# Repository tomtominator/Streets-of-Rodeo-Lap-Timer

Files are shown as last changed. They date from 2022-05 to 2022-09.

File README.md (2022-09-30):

# Streets-of-Rodeo-Lap-Timer

## Project Description  

As a de-stressing pastime, my brother and I ride our bikes around our driveway as fast as we can. How fast? This project helps us answer that question with precision. Our motion detecting lap timer is made from a custom built 4 digit 7 segement display for the timer, an ultrasonic distance sensor, and a cheap microcontroller. Its designed to be powered from a wall outlet. It consisted of lots of soldering LEDs, 3D printing for the LED cases, circuit design to ensure we weren't frying the microcontroller, and C++ code writing.  

### High Level Design Choices: 

The initial idea was to use a laser-type sensor that would trigger when we passed through. It wasn't ideal to have to place objects on both sides and possibly even have a wire tracing back over the track. I remembered using sonic distance sensors in physics class which only had 1 emitter fixing our problem. I also remembered them being suprisingly accurate and we only needed rough accuracy for our application. We happened to have a ultrasonic distance sensor and microcontroller lying around so we built the project around that.  

The original plan was to buy a 7 segment display but the largest ones our local [All Electronics](https://www.allelectronics.com/) had were 1"x3". We got this design working quickly but were unsatisfied because we couldn't easily see the digits during the day or while going around the driveway. So we build our own display using a modified design of the one we bought. Based on our calculations, this new display would draw about 1-1.5A which introduced a lot of problems with the initial design. We had to use transistors because the microcontroller couldn't provide the power needed through its pins, we needed to connect to an outside power source and provide 2 seperate voltages (1 for the board and 1 for the LEDS), and we needed to decide on the LED layout and soldering method for 200 some LEDS.  

Check out an older project: https://github.com/tomtominator/UnderglowProject  

## Finished Product

### Wooden Case and Sensor Case (Penguin)

Picture of box and punguin sensor 

Display board mounded to plywood box with main power switch and brightness dimmer mounted on the right side. The box is spray painted black to match the segments for a clean and professional look. A penguin themed 3d printed case for the distance sensor, raises it to the optimal 4 inches from the ground. Universal 3 prong power female power cable and 4 prong female sensor connectors are mounted on the bottom for easy setup and swappable cables.

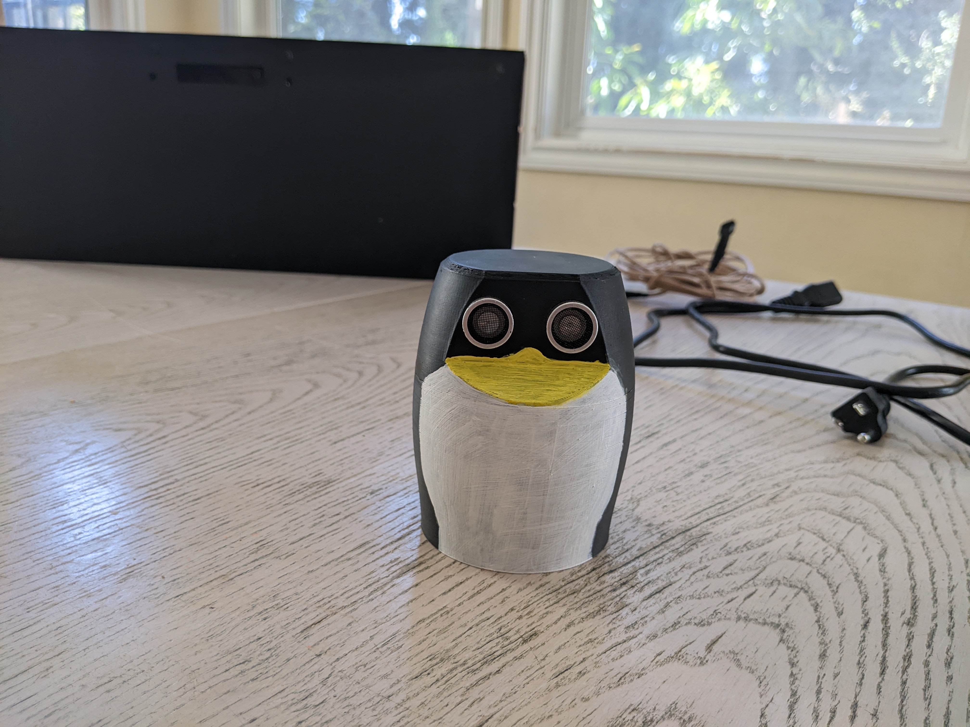
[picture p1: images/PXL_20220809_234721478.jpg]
Close up of penguin
 

Close up of penguin theme sensor case.

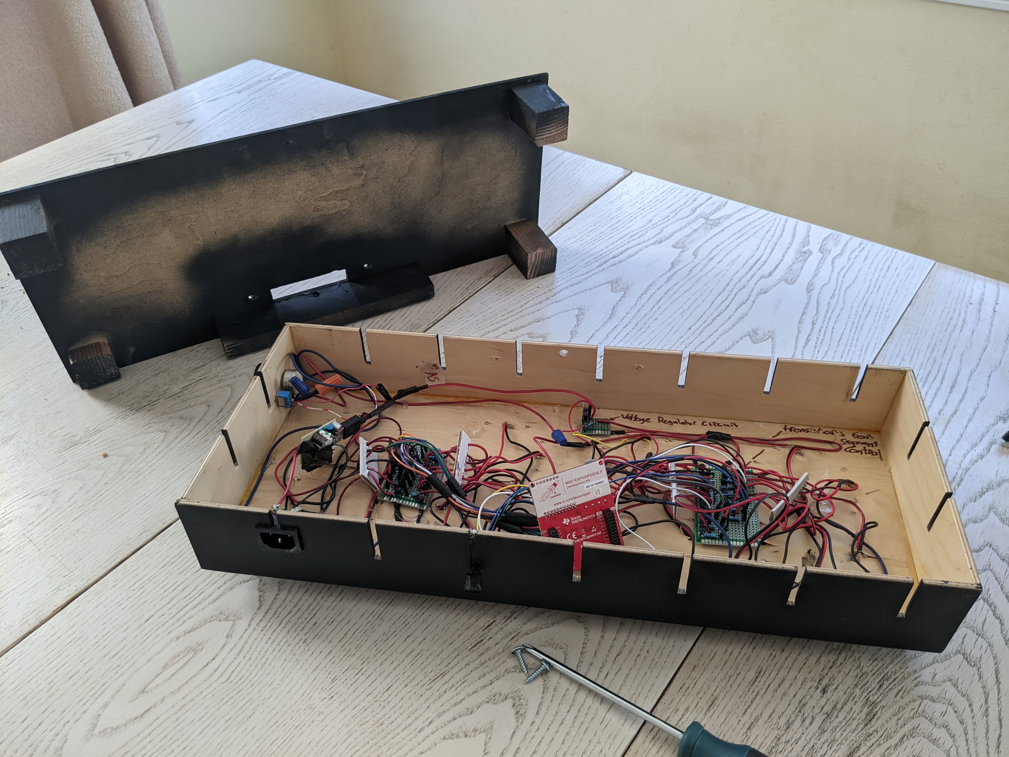
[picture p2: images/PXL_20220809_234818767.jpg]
Picture wooden case with back removed


View of the back cover easliy removed with the extraction of two screws on top of the case gives easy access to all components inside. 

# Detailed Construction

## Display

We modeled our custom 7 segment display off of this one we bought. It is a common anode display. This datasheet was useful: https://www.allelectronics.com/mas_assets/media/allelectronics2018/spec/FDA-5.pdf
### Circuit Diagrams
  
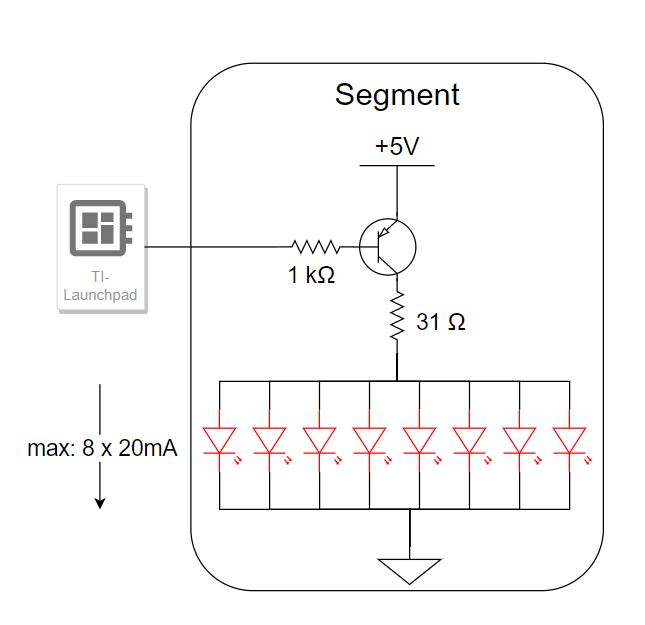
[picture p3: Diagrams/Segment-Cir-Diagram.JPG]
Segment Diagram
  

Above is the circuit diagram for a given segment. We will be running the LEDS at 20mA and controlling the segments with a PNP transistor switched by the launchpad. The 31 ohms was calculated to get the desired 20mA/LED number.

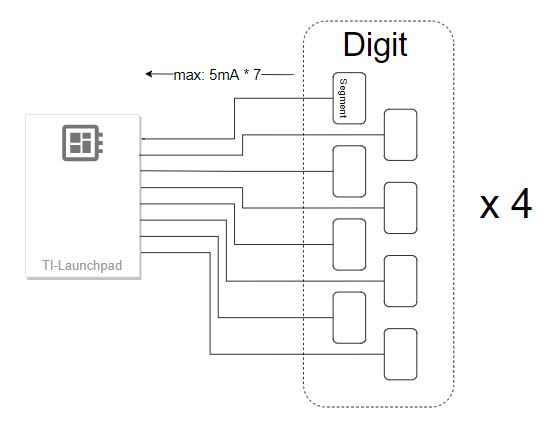
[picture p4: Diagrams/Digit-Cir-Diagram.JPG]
Digit Diagram
   

The 5mA current coming into the board per transistor is calculated using the hfe number provided by the transistor datasheet and this equation: I_C = (hfe) * I_B. For a PNP we are sinking current. The total current into the board is 35mA. The board must only dissapate about .175W. Note that only 1 digit is ever on at a time. The total draw of the digit from the power source is 160mA * 7 = 1.12A --at 5V--> 5.6W  

Our 7 segment display was slightly different from the standard design to make wiring easier. However, this made the pinout quite busy:  

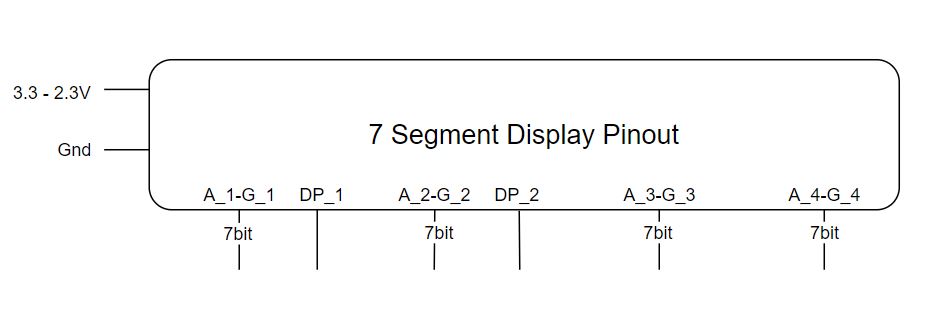
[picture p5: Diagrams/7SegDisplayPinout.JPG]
Custom 7 Segment Display Pinout
   

Luckily the launchpad has many i/o pins so this simplified our hardware and lighting up a sigle digit at a time could be done in the code (this single digit lighting is done to save on power and limit the current the launchpad has to sink).  
The distance sensor was connected to the launchpad as well. The whole assembly was controlled by C++ code run on the launchpad, switching all the segments and operating the distance sensor.
  
### Experimental Results

- Total segment current = 100mA - less than expected  
- Current into base of 2N3905 = 3.5mA  
- Transistor base resistance: 150 || 270 = 96 ohms  
- No need for resistors for each LED, the transistor base resistor on limits the current flow from emitter to collector  
- LEDS plenty bright at this power level, likely want to be able to reduce brightness with pot somehow

These results will give a general estimate to make sure we don't exceed any of our parts power limits. This is also a sanity check that calculations were done correctly.  

### Display Brightness

We had to use a voltage regulator to provide both 5 and a variable 3.3-2.3V from the 5V power supply. We used the LM317 variable voltage regulator with a 10K potentionmeter. This explanation video was extremely helpful: https://www.youtube.com/watch?v=IjJWWGPjc-w.  

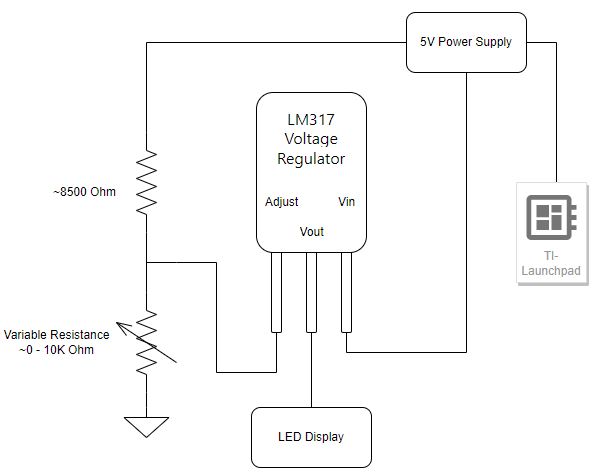
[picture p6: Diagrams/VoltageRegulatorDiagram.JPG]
Voltage Regulator Diagram
   

# Sensor and Code

The final version of the [code on the Launchpad](https://github.com/tomtominator/Streets-of-Rodeo-Lap-Timer/blob/main/LaunchPad%20Code/Lap_Time_Display_Custom_Final/Lap_Time_Display_Custom_Final.ino). The microcontroller was under-powered for the desired rapid operation of both the display and distance sensor. We worked to optimize the multitasking balance to get a solid display with rapid sensing for accurate lap times. Within the limitations of our materials I am satisfied but we have future plans to have 2 slow microcontrollers each doing one task and communicating (perhaps over wifi with the ardunio W). 

The operation of the distance sensor is slightly complicated but luckily there is plenty of code on the internet for this sensor. This is the explanation we used and base code we modified: https://create.arduino.cc/projecthub/abdularbi17/ultrasonic-sensor-hc-sr04-with-arduino-tutorial-327ff6  

Future Improvements:  
Make main loop event driven by performing certain functions every amount of millis() difference, instead of using counters to trigger actions. (This way we actually sample every 200ms for example)  
Make one of the digits a lap counter since we don't have hundreds place precision

# Physical Parts

### STL Files Descriptions

- 1 Segment File
Includes 8 holes for each led to be inserted and soldered on the back

- Slip in Plate
Accepts 1 segment plate to slip in firmly, allowing space for soldered connections. Wires are to be routed through the center hole in the back. Other 2 holes used for mounting to final backplate.

- 1 digit linked
Not included in our final design but would save alot of time and effort. Instead of printing segments individually this file includes 7 connected with proper spacing. Recommended for printers with ABL or a very nicely leveled bed. 

### Assembly
After 8 LEDs are soldered in paralell in each segment, power wires can be routed through the slip in plate, and the segment can be firmly inserted. (If using the individual plates, each should be mounted to a backplate prior to doing this.) 

Each segment with LEDs and power wires are pressed into their plates and all wires are routed through the slip in plate and through holes drilled in the backplate. All wires are easily accesable in the backplate for later connections to transistors and board. 

Segments could be painted matt black for a cleaner look.

All switches and pots can be mounted on the backplate 

# Links

## Ingredients:  

- HC-SR04 Ultrasonic Distance Sensor: https://www.amazon.com/SainSmart-HC-SR04-Ranging-Detector-Distance/dp/B004U8TOE6 
- 4-Digit 7 Segement Display (Deprecated): https://www.allelectronics.com/item/fda-5/4-digit-red-clock-display-0.4-digits/1.html  
- TI Launchpad MSP-EXP430F5529LP: https://www.ti.com/tool/MSP-EXP430F5529LP
- 232 Red LEDS: https://www.allelectronics.com/item/led-513/5mm-red-led/1.html
- 30 PNP Transistors: https://www.allelectronics.com/item/2n3905/2n3905-pnp-to-92-transistor/1.html
- LM317 Voltage Regulator
- Switch, 10K pot, lots of resistors(mostly 270ohm)

### Spec/Datasheets:  

- Transistors: https://www.mouser.com/datasheet/2/308/FairchildSemiconductor_16142055386277-1191860.pdf
- LEDS: https://www.allelectronics.com/mas_assets/media/allelectronics2018/spec/LED-513.pdf
- Launchpad: https://www.ti.com/lit/ug/slau533d/slau533d.pdf?ts=1653799657399
- Sensor: https://web.eece.maine.edu/~zhu/book/lab/HC-SR04%20User%20Manual.pdf
- Display: https://www.allelectronics.com/mas_assets/media/allelectronics2018/spec/FDA-5.pdf
- Voltage Regulator: https://www.ti.com/document-viewer/LM317A/datasheet/features-snvsac20075#SNVSAC20075

Daniel and Thomas Matthew 2022

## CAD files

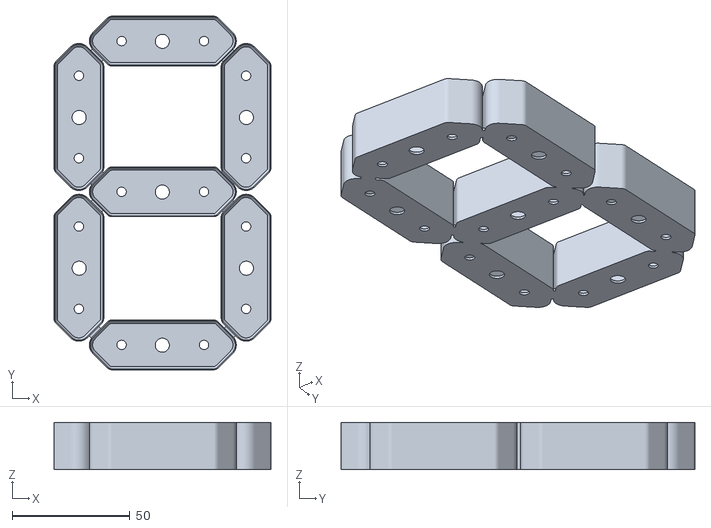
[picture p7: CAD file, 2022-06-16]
CAD Files/1 Digit linked.stl
92.1 x 150.1 x 20.0

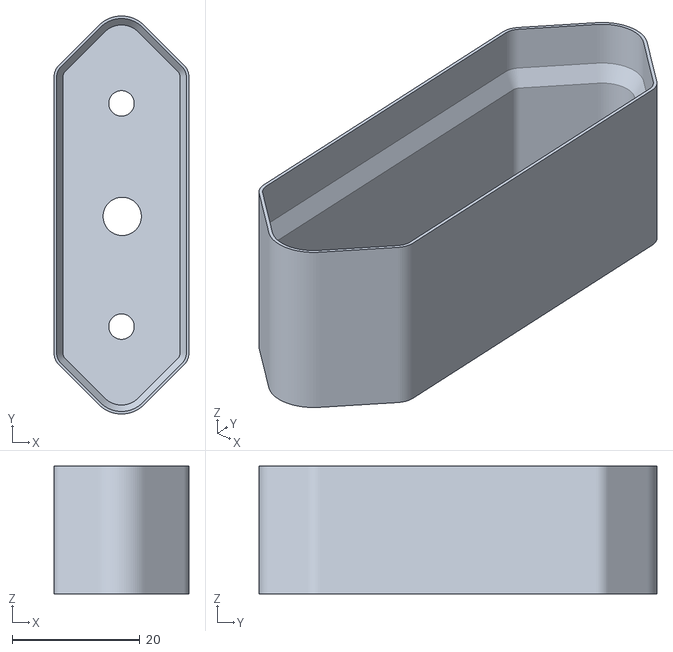
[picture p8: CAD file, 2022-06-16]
CAD Files/Slip In plate V2.stl
21.1 x 62.4 x 20.0

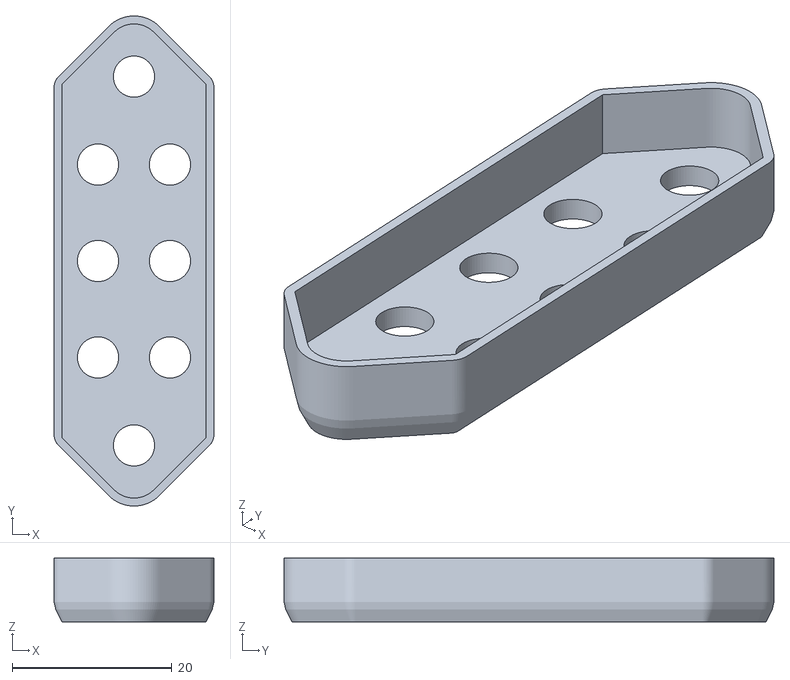
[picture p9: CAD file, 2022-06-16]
CAD Files/1 Segment V2.stl
20.0 x 61.3 x 8.00

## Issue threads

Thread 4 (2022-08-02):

Use Arduino Threads for Multitasking

tomtominator, 2022-08-02:
Improve main loop code with (Arduino Threads)[https://github.com/arduino-libraries/Arduino_Threads].

Benefits:
- Code easier to read
- Lower power
- can use with multiple cores in a future upgrade
- faster?

jfmatth, 2022-08-03:
This from the same article, might be an alternative

https://docs.arduino.cc/tutorials/generic/multiple-blinks

tomtominator, 2022-08-11:
It looks like the scheduler is only supported by Arduinos with SAMD architectures. Same thing with the threads. The chip on the TI board is not as powerful as I thought:
Our chip: https://www.ti.com/product/MSP430F5529#features
Ardunio Zero: https://www.microchip.com/en-us/product/ATsamd21g18

Might want to upgrade to the zero or similar ardunio...

jfmatth, 2022-08-11:
might be worth the upgrade (10bucks) just to use the library.

tomtominator, 2022-08-12:
A bit more than 10bucks, I think Daniel and I would rather go all in and get 2 Arduinos with Wifi and put 1 in the penguin.

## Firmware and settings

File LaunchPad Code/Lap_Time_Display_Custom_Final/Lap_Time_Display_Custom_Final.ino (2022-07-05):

// ---------- Lap Time Counter ----------
// Using Ultrasonic Sensor HC-SR04
// Base sensor code taken from: https://create.arduino.cc/projecthub/abdularbi17/ultrasonic-sensor-hc-sr04-with-arduino-tutorial-327ff6
// MSQC4911C Display data sheet: https://www.allelectronics.com/mas_assets/media/allelectronics2018/spec/FDA-5.pdf
//   Note: our custom display has a wire for each of the 30 segments (7 segment * 4 digit + 2 decimal places) where LOW = on, HIGH = off
//    but we only power 1 digit at a time to limit how much current the microcontroller has to sink. Powering 1 digit it sinks about 45mA
//   Note 2: pins 6_1 and 6_2 on the microcontroller don't work; can't write a high value to them

// Written by: Thomas Matthew 6/6/2022
// Last Updated: 7/1/22

// --- Feature Flags ---
// 1/0 values for enable/disable of certain sections of the code
#define DEBUG 0 // Enables/disables serial communication with computer for debugging


// --- End ---

//---Parameters---
// Note: all delays are estimates that don't include the time to execute the code, only the 'delay' lines. So they are bound to be lower than actual
#define REFRESH_RATE 20 // Decrease REFRESH_RATE to refresh digits quicker and sample more often
                        // Digit refreshes every REFERSH_RATE/4 and distance sensor samples evert REFERSH_RATE
                        // Note 1: LAP_COOLDOWN dependency on REFRESH_RATE
                        // Note 2: that sensor operation takes some time between displaying the digits but it micro sec vs milli sec (if sensor is not working properly it will be significant amount of time)
#define DIGIT_UPDATE_COOLDOWN 5 // Update ongoing_lap_time and displayed digits every DIGIT_UPDATE_COOLDOWN * REFRESH_RATE(20) = 100ms = .1sec
#define SENSE_COOLDOWN 10 // Only operate the sensor every SENSE_COOLDOWN loops of the main loop (sense rate: SENSE_COOLDOWN * REFRESH_RATE = 200ms)
#define LAP_COOLDOWN 125 //Laps can happen only every LAP_COOLDOWN(125) * REFRESH_RATE(20) = 2.5 sec
#define PASS_DIS_CHANGE 30 // Distance decreases by this much for a valid pass - lower to make more sensitive. Raise to decrease noise
#define WOBBLE 10 // Distance sensor must change by more than this to even consider an object has passed
//---End Parameters---

// ---------------- LAP TIME MEASUREMENT + HC-SR04 SECTION ----------------

#define echoPin P8_2
#define trigPin P8_1

// Variables for distance sensor
long duration; // duration of sound wave travel
int distance; //  distance measurement
int last_distance;
int laps; // number of times a object passes
int lap_cooldown_cnt;
int sense_cooldown_cnt;
int digit_update_cooldown_cnt;

float lap_time; //Lap time in ms
float ongoing_lap_time;
long lap_start;
long lap_end;
// ---------------- END ----------------


// ---------------- CUSTOM 7 SEGMENT DISPLAY SECTION ----------------

// Unfortunate Note: ABC.. wiring is reflected across xy plane. 
//                   Ording of letters represents ordering of wires into the microcontroller. ie P6_5 is adjacent to P3_4. and 6_5 was originally meant to be segment A_1
//                   ABCDEFG -> ECBAFEG (this is not the case for all digits) (we were rushed when wiring this unfortunately)
//                   (for digit 1 FEG -> GEF)
// Digit Pins:
  //1st Digit  
  #define D_1 P6_5 // blue
  #define C_1 P3_4 // 
  #define B_1 P3_3 // 
  #define A_1 P1_6 // 
  #define G_1 P6_6 // 
  #define E_1 P3_2 // 
  #define F_1 P2_7 // red 
  #define DP_1 P3_5 // black
  //2nd Digit
  #define D_2 P6_0 // purple 
  #define C_2 P6_1 // 
  #define B_2 P4_0 // 
  #define A_2 P4_2 // 
  #define F_2 P6_4 // 
  #define E_2 P7_0 // 
  #define G_2 P3_6 // black
  #define DP_2 P4_1 // red
  //3rd Digit //ABCDEF->GEFABCD
  #define G_3 P2_5 // black
  #define E_3 P2_4 // 
  #define F_3 P1_5 // 
  #define A_3 P1_4 // 
  #define B_3 P1_3 // 
  #define C_3 P1_2 // 
  #define D_3 P4_3 // gray
  //4th Digit
  #define D_4 P2_0 // red
  #define C_4 P2_2 // 
  #define B_4 P7_4 // 
  #define A_4 P3_0 // 
  #define F_4 P3_1 // 
  #define E_4 P2_6 // 
  #define G_4 P2_3 // orange


// Truth table for segements for digit
// ith Row holds the segments for the ith digit in A,B,C, ... order
// 1 value indicates light up that segment
int dsegs[10][7] = {
  {1, 1, 1, 1, 1, 1, 0}, /*0*/
  {0, 1, 1, 0, 0, 0, 0}, /*1*/
  {1, 1, 0, 1, 1, 0, 1}, /*2*/
  {1, 1, 1, 1, 0, 0, 1}, /*3*/
  {0, 1, 1, 0, 0, 1, 1}, /*4*/
  {1, 0, 1, 1, 0, 1, 1}, /*5*/
  {1, 0, 1, 1, 1, 1, 1}, /*6*/
  {1, 1, 1, 0, 0, 0, 0}, /*7*/
  {1, 1, 1, 1, 1, 1, 1}, /*8*/
  {1, 1, 1, 1, 0, 1, 1}  /*9*/
  };

//Decimal number to be displayed (converted to display_*)
float display_number;
int temp;

// These set what digits are being displayed
int display_digit_1;
int display_digit_2;
int display_digit_3;
int display_digit_4;
int decimal_place; //encodes where to place decimal point
// (1, ones number, 2 tens number, 3 hundreds number, 4 thousands number)
// ---------------- END ----------------

void setup() {
  laps = 1;
  pinMode(trigPin, OUTPUT);
  pinMode(echoPin, INPUT);
  if (DEBUG) {
    Serial.begin(9600); 
    Serial.println("Ultrasonic Sensor HC-SR04 Test"); 
    Serial.println("with TI Launchpad MSP-EXP430F5529LP");
  }

  lap_cooldown_cnt = 0;
  sense_cooldown_cnt = 0;
  digit_update_cooldown_cnt = 0;

  // ----------------------------------------------------
  pinMode(A_1, OUTPUT);
  pinMode(B_1, OUTPUT);
  pinMode(C_1, OUTPUT);
  pinMode(D_1, OUTPUT);
  pinMode(E_1, OUTPUT);
  pinMode(F_1, OUTPUT);
  pinMode(G_1, OUTPUT);
  pinMode(DP_1, OUTPUT);

  pinMode(A_2, OUTPUT);
  pinMode(B_2, OUTPUT);
  pinMode(C_2, OUTPUT);
  pinMode(D_2, OUTPUT);
  pinMode(E_2, OUTPUT);
  pinMode(F_2, OUTPUT);
  pinMode(G_2, OUTPUT);
  pinMode(DP_2, OUTPUT);

  pinMode(A_3, OUTPUT);
  pinMode(B_3, OUTPUT);
  pinMode(C_3, OUTPUT);
  pinMode(D_3, OUTPUT);
  pinMode(E_3, OUTPUT);
  pinMode(F_3, OUTPUT);
  pinMode(G_3, OUTPUT);
  //pinMode(DP_3, OUTPUT); no DP 3

  pinMode(A_4, OUTPUT);
  pinMode(B_4, OUTPUT);
  pinMode(C_4, OUTPUT);
  pinMode(D_4, OUTPUT);
  pinMode(E_4, OUTPUT);
  pinMode(F_4, OUTPUT);
  pinMode(G_4, OUTPUT);
  //pinMode(DP_4, OUTPUT); no DP 4
}

void loop() {
  
  // Get Time + Operate Sensor:
  if (lap_cooldown_cnt > LAP_COOLDOWN && digit_update_cooldown_cnt > DIGIT_UPDATE_COOLDOWN) {
    //----Lap Time Measurement----
    lap_end = millis();
    ongoing_lap_time = lap_end - lap_start;
    ongoing_lap_time = ongoing_lap_time / 1000;
    digit_update_cooldown_cnt = 0;

    // ---- SENSE ----
    if (sense_cooldown_cnt > SENSE_COOLDOWN) {
      sense_cooldown_cnt = 0;

      //----Measure Distance using HC-SR04----
      digitalWrite(trigPin, LOW); // Clears the trigPin condition
      delayMicroseconds(2);
      digitalWrite(trigPin, HIGH); // Sets the trigPin HIGH (ACTIVE) for 10 microseconds
      delayMicroseconds(10);
      digitalWrite(trigPin, LOW);
      duration = pulseIn(echoPin, HIGH); // Reads the echoPin, returns the sound wave travel time in microseconds
      // Calculating the distance
      distance = duration * 0.034 / 2; // Speed of sound wave divided by 2 (go and back)
      if (DEBUG) {
        Serial.print("Sensed Distance:  ");
        Serial.println(distance);
        Serial.print("Last Distance:  ");
        Serial.println(last_distance);
      }
      // Object Passed if distance decreased by at least PASS_DIS_CHANGE 
      //    Note: object must be further than PASS_DIS_CHANGE
      if ((distance - PASS_DIS_CHANGE) > 0 && !((last_distance - WOBBLE) < distance && distance < (last_distance + WOBBLE)) && (distance - PASS_DIS_CHANGE) < last_distance) { 
        lap_time = ongoing_lap_time;
        laps = laps + 1;
        lap_cooldown_cnt = 0;
        lap_start = millis();
        if (DEBUG) {
          Serial.println("------------------------Object passed----------------------");
          Serial.print("Lap Number: ");
          Serial.println(laps);
          Serial.print("Lap Time: ");
          Serial.println(lap_time);
        }
      }
      last_distance = distance;
    }
  }

  // Update Counters:
  lap_cooldown_cnt = lap_cooldown_cnt + 1;
  sense_cooldown_cnt = sense_cooldown_cnt + 1;
  digit_update_cooldown_cnt = digit_update_cooldown_cnt + 1;


  // ------------------- DISPLAY RECORDED TIME -------------------

  // Update Digit we are Displaying:
  if (sense_cooldown_cnt == 1 || lap_cooldown_cnt == 1 || digit_update_cooldown_cnt == 1) {
    //Display lap time for [LAP_COOLDOWN] seconds after object passes
    // else display the time spent in current lap
    if (lap_cooldown_cnt < LAP_COOLDOWN) {
      display_number = lap_time;
    } else {
      display_number = ongoing_lap_time;
    }

    //Get the first 4 digits of input unsigned long
    if (display_number > 1000) {      temp = display_number;          decimal_place = 4;
    } else if(display_number > 100) { temp = display_number * 10;     decimal_place = 3;
    } else if(display_number > 10) {  temp = display_number * 100;    decimal_place = 2;
    } else {                        temp = display_number * 1000;   decimal_place = 1; }
    display_digit_1 = temp / 1000;
    display_digit_2 = (temp / 100) % 10;
    display_digit_3 = (temp / 10) % 10;
    display_digit_4 = temp % 10;
  }
  
  // --- DISPLAY DIGITS ---
  // by scanning through them
  // --- 1st Digit ---
  if (dsegs[display_digit_1][0] == 1) { digitalWrite(A_1, LOW); } else { digitalWrite(A_1, HIGH); }
  if (dsegs[display_digit_1][1] == 1) { digitalWrite(B_1, LOW); } else { digitalWrite(B_1, HIGH); }
  if (dsegs[display_digit_1][2] == 1) { digitalWrite(C_1, LOW); } else { digitalWrite(C_1, HIGH); }
  if (dsegs[display_digit_1][3] == 1) { digitalWrite(D_1, LOW); } else { digitalWrite(D_1, HIGH); }
  if (dsegs[display_digit_1][4] == 1) { digitalWrite(E_1, LOW); } else { digitalWrite(E_1, HIGH); }
  if (dsegs[display_digit_1][5] == 1) { digitalWrite(F_1, LOW); } else { digitalWrite(F_1, HIGH); }
  if (dsegs[display_digit_1][6] == 1) { digitalWrite(G_1, LOW); } else { digitalWrite(G_1, HIGH); }
  if (decimal_place == 1 ) { digitalWrite(DP_1, LOW); } else { digitalWrite(DP_1, HIGH); }

  delay(REFRESH_RATE/4);
  //Turn off digit:
  digitalWrite(A_1, HIGH);
  digitalWrite(B_1, HIGH);
  digitalWrite(C_1, HIGH);
  digitalWrite(D_1, HIGH);
  digitalWrite(E_1, HIGH);
  digitalWrite(F_1, HIGH);
  digitalWrite(G_1, HIGH);
  digitalWrite(DP_1, HIGH);

  // --- 2nd Digit ---
  if (dsegs[display_digit_2][0] == 1) { digitalWrite(A_2, LOW); } else { digitalWrite(A_2, HIGH); }
  if (dsegs[display_digit_2][1] == 1) { digitalWrite(B_2, LOW); } else { digitalWrite(B_2, HIGH); }
  if (dsegs[display_digit_2][2] == 1) { digitalWrite(C_2, LOW); } else { digitalWrite(C_2, HIGH); }
  if (dsegs[display_digit_2][3] == 1) { digitalWrite(D_2, LOW); } else { digitalWrite(D_2, HIGH); }
  if (dsegs[display_digit_2][4] == 1) { digitalWrite(E_2, LOW); } else { digitalWrite(E_2, HIGH); }
  if (dsegs[display_digit_2][5] == 1) { digitalWrite(F_2, LOW); } else { digitalWrite(F_2, HIGH); }
  if (dsegs[display_digit_2][6] == 1) { digitalWrite(G_2, LOW); } else { digitalWrite(G_2, HIGH); }
  if (decimal_place == 2 ) { digitalWrite(DP_2, LOW); } else { digitalWrite(DP_2, HIGH); }

  delay(REFRESH_RATE/4);
  //Turn off digit:
  digitalWrite(A_2, HIGH);
  digitalWrite(B_2, HIGH);
  digitalWrite(C_2, HIGH);
  digitalWrite(D_2, HIGH);
  digitalWrite(E_2, HIGH);
  digitalWrite(F_2, HIGH);
  digitalWrite(G_2, HIGH);
  digitalWrite(DP_2, HIGH);

  // --- 3rd Digit ---
  if (dsegs[display_digit_3][0] == 1) { digitalWrite(A_3, LOW); } else { digitalWrite(A_3, HIGH); }
  if (dsegs[display_digit_3][1] == 1) { digitalWrite(B_3, LOW); } else { digitalWrite(B_3, HIGH); }
  if (dsegs[display_digit_3][2] == 1) { digitalWrite(C_3, LOW); } else { digitalWrite(C_3, HIGH); }
  if (dsegs[display_digit_3][3] == 1) { digitalWrite(D_3, LOW); } else { digitalWrite(D_3, HIGH); }
  if (dsegs[display_digit_3][4] == 1) { digitalWrite(E_3, LOW); } else { digitalWrite(E_3, HIGH); }
  if (dsegs[display_digit_3][5] == 1) { digitalWrite(F_3, LOW); } else { digitalWrite(F_3, HIGH); }
  if (dsegs[display_digit_3][6] == 1) { digitalWrite(G_3, LOW); } else { digitalWrite(G_3, HIGH); }
  
  delay(REFRESH_RATE/4);
  digitalWrite(A_3, HIGH);
  digitalWrite(B_3, HIGH);
  digitalWrite(C_3, HIGH);
  digitalWrite(D_3, HIGH);
  digitalWrite(E_3, HIGH);
  digitalWrite(F_3, HIGH);
  digitalWrite(G_3, HIGH);

// -- 4th Digit ---
  if (dsegs[display_digit_4][0] == 1) { digitalWrite(A_4, LOW); } else { digitalWrite(A_4, HIGH); }
  if (dsegs[display_digit_4][1] == 1) { digitalWrite(B_4, LOW); } else { digitalWrite(B_4, HIGH); }
  if (dsegs[display_digit_4][2] == 1) { digitalWrite(C_4, LOW); } else { digitalWrite(C_4, HIGH); }
  if (dsegs[display_digit_4][3] == 1) { digitalWrite(D_4, LOW); } else { digitalWrite(D_4, HIGH); }
  if (dsegs[display_digit_4][4] == 1) { digitalWrite(E_4, LOW); } else { digitalWrite(E_4, HIGH); }
  if (dsegs[display_digit_4][5] == 1) { digitalWrite(F_4, LOW); } else { digitalWrite(F_4, HIGH); }
  if (dsegs[display_digit_4][6] == 1) { digitalWrite(G_4, LOW); } else { digitalWrite(G_4, HIGH); }

  delay(REFRESH_RATE/4);
  digitalWrite(A_4, HIGH);
  digitalWrite(B_4, HIGH);
  digitalWrite(C_4, HIGH);
  digitalWrite(D_4, HIGH);
  digitalWrite(E_4, HIGH);
  digitalWrite(F_4, HIGH);
  digitalWrite(G_4, HIGH);



  // ------------------------------------------------------------
  //delay(REFRESH_RATE);
}

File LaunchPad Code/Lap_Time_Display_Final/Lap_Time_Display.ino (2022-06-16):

// ---------- Lap Time Counter ----------
// Using Ultrasonic Sensor HC-SR04
// Base code taken from: https://create.arduino.cc/projecthub/abdularbi17/ultrasonic-sensor-hc-sr04-with-arduino-tutorial-327ff6
// MSQC4911C Display data sheet: https://www.allelectronics.com/mas_assets/media/allelectronics2018/spec/FDA-5.pdf
// Written by: Thomas Matthew 5/27/2022


// ---------------- LAP TIME MEASUREMENT + HC-SR04 SECTION ----------------
#define echoPin P6_0
#define trigPin P6_1


#define SAMPLE_RATE 50 //Sample every 50ms = .05s
#define LAP_COOLDOWN 40 //Laps can happen only every LAP_COOLDOWN * SAMPLE_RATE (= 2) sec

#define WOBBLE 5 // Must change more than this range to be considered a real change in measured distance
#define PASS_DIS_CHANGE 30 // Distance decreases by this much for a valid pass - lower to make more sensitive. Raise to decrease noise

// Define Variables
long duration; // duration of sound wave travel
int distance; //  distance measurement
int last_distance;
int laps; // number of times a object passes
int lap_cooldown_cnt;

float lap_time; //Lap time in ms
float ongoing_lap_time;
long lap_start;
long lap_end;
// ---------------- END ----------------



// ---------------- 7 SEGMENT DISPLAY SECTION ----------------
#define digit_1 P2_5 // pin 1
#define digit_2 P8_2 // 2
#define digit_3 P2_3 // 6
#define digit_4 P8_1 // 8
#define A P1_4 // 14
#define B P2_4 // 16
#define C P1_3 // 13
#define D P4_3 // 3
#define E P4_0 // 5
#define F P1_2 // 11
#define G P1_5 // 15
#define DP P3_7 // 7

//#define SWITCHING_SPEED 10 //how quickly rotates between digits in ms
// = SAMPLE_RATE/4

// Truth table for segements for digit
// ith Row holds the segments for the ith digit in A,B,C, ... order
// 1 value indicates light up that segment
int dsegs[10][7] = {
  {1, 1, 1, 1, 1, 1, 0}, /*0*/
  {0, 1, 1, 0, 0, 0, 0}, /*1*/
  {1, 1, 0, 1, 1, 0, 1}, /*2*/
  {1, 1, 1, 1, 0, 0, 1}, /*3*/
  {0, 1, 1, 0, 0, 1, 1}, /*4*/
  {1, 0, 1, 1, 0, 1, 1}, /*5*/
  {1, 0, 1, 1, 1, 1, 1}, /*6*/
  {1, 1, 1, 0, 0, 0, 0}, /*7*/
  {1, 1, 1, 1, 1, 1, 1}, /*8*/
  {1, 1, 1, 1, 0, 1, 1}  /*9*/
  };

//Decimal number to be displayed (converted to display_*)
float display_number;
int temp;

// These set what digits are being displayed
int display_digit_1;
int display_digit_2;
int display_digit_3;
int display_digit_4;
int decimal_place; //encodes where to place decimal point
// (1, ones number, 2 tens number, 3 hundreds number, 4 thousands number)
// ---------------- END ----------------


void setup() {
  laps = 1;
  pinMode(trigPin, OUTPUT);
  pinMode(echoPin, INPUT);
  Serial.begin(9600); 
  Serial.println("Ultrasonic Sensor HC-SR04 Test"); 
  Serial.println("with TI Launchpad MSP-EXP430F5529LP");

  // ----------------------------------------------------

  pinMode(digit_1, OUTPUT);
  pinMode(digit_2, OUTPUT);
  pinMode(digit_3, OUTPUT);
  pinMode(digit_4, OUTPUT);
  pinMode(A, OUTPUT);
  pinMode(B, OUTPUT);
  pinMode(C, OUTPUT);
  pinMode(D, OUTPUT);
  pinMode(E, OUTPUT);
  pinMode(F, OUTPUT);
  pinMode(G, OUTPUT);
  pinMode(DP, OUTPUT);
}

void loop() {

  //----Measure Distance using HC-SR04----
  digitalWrite(trigPin, LOW); // Clears the trigPin condition
  delayMicroseconds(2);
  digitalWrite(trigPin, HIGH); // Sets the trigPin HIGH (ACTIVE) for 10 microseconds
  delayMicroseconds(10);
  digitalWrite(trigPin, LOW);
  duration = pulseIn(echoPin, HIGH); // Reads the echoPin, returns the sound wave travel time in microseconds
  // Calculating the distance
  distance = duration * 0.034 / 2; // Speed of sound wave divided by 2 (go and back)


  //----Lap Time Measurement----
  lap_end = millis();
  ongoing_lap_time = lap_end - lap_start;
  ongoing_lap_time = ongoing_lap_time / 1000;
   
  //Check that distance has changed outside of some range to account for noise and see if the measured distance has gotten a lot closer
  if (lap_cooldown_cnt > LAP_COOLDOWN && (distance - PASS_DIS_CHANGE) > 0 && !((last_distance - WOBBLE) < distance && distance < (last_distance + WOBBLE)) && (distance - PASS_DIS_CHANGE) < last_distance) { 
    lap_time = ongoing_lap_time;
    Serial.println("------------------------Object passed----------------------");
    Serial.print("Lap Number: ");
    Serial.println(laps);
    Serial.print("Lap Time: ");
    Serial.println(lap_time);
    
    laps = laps + 1;
    lap_cooldown_cnt = 0;
    lap_start = millis();
  }

  last_distance = distance;
  lap_cooldown_cnt = lap_cooldown_cnt + 1;

  // ------------------- DISPLAY RECORDED TIME -------------------

  //Display lap time for [LAP_COOLDOWN] seconds after object passes
  // else display the time spent in current lap
  if (lap_cooldown_cnt < LAP_COOLDOWN) {
    display_number = lap_time;
  } else {
    display_number = ongoing_lap_time;
  }
  

  
  //Get the first 4 digits of input float
  if (display_number > 1000) {      temp = display_number;          decimal_place = 4;
  } else if(display_number > 100) { temp = display_number * 10;     decimal_place = 3;
  } else if(display_number > 10) {  temp = display_number * 100;    decimal_place = 2;
  } else {                        temp = display_number * 1000;   decimal_place = 1; }
  display_digit_1 = temp / 1000;
  display_digit_2 = (temp / 100) % 10;
  display_digit_3 = (temp / 10) % 10;
  display_digit_4 = temp % 10;
 
  
  //1st Digit:
  digitalWrite(digit_1, HIGH);
  digitalWrite(digit_2, LOW);
  digitalWrite(digit_3, LOW);
  digitalWrite(digit_4, LOW);
  if (dsegs[display_digit_1][0] == 1) { digitalWrite(A, LOW); } else { digitalWrite(A, HIGH); }
  if (dsegs[display_digit_1][1] == 1) { digitalWrite(B, LOW); } else { digitalWrite(B, HIGH); }
  if (dsegs[display_digit_1][2] == 1) { digitalWrite(C, LOW); } else { digitalWrite(C, HIGH); }
  if (dsegs[display_digit_1][3] == 1) { digitalWrite(D, LOW); } else { digitalWrite(D, HIGH); }
  if (dsegs[display_digit_1][4] == 1) { digitalWrite(E, LOW); } else { digitalWrite(E, HIGH); }
  if (dsegs[display_digit_1][5] == 1) { digitalWrite(F, LOW); } else { digitalWrite(F, HIGH); }
  if (dsegs[display_digit_1][6] == 1) { digitalWrite(G, LOW); } else { digitalWrite(G, HIGH); }
  if (decimal_place == 1 ) { digitalWrite(DP, LOW); } else { digitalWrite(DP, HIGH); }

  delay(SAMPLE_RATE/4);
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

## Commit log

2022-05-30 Preliminary Circuit Diagrams
2022-06-16 Add STL Files (#2)
    * Add STL files
    * Add STL section to README.md
    [1 Digit linked.stl, 1 Segment V2.stl, Slip In plate V2.stl]
2022-06-16 Voltage Regulator Diagram
2022-06-19 Write ino file to use display only
    This file can now be used to test the display without the inclusion of the distance sensor to narrow down bugs
    [Stopwatch_Custom_7seg.ino]
2022-06-19 Efficiency update to code to prevent flickering
    The distance sensor was taking too long to operate and messing with the display of the digits. Now it only senses every SENSE_COOLDOWN(=10) executions of the loop. This way we spend more time displaying the digits without the execution of the distance sensor in between and this will make the display brighter because it is on more of the time.
    [Lap_Time_Display_Custom_Final.ino]
2022-06-21 Fix lap time type error
    millis() returns an unsigned long but our desired type is float for the lap time variable. Simply set all the lap time variables to float and millis() and the digit parser will work properly
    [Lap_Time_Display_Custom_Final.ino]
2022-07-01 Fix attempt 1: change display digit update logic, change parameters: REFRESH, SENSE/LAP cooldowns
    [Lap_Time_Display_Custom_Final.ino]
2022-07-05 Fix some bad changes made during the efficiency update
    I had taken out where last_distance was updated and removed the WOBBLE test on a passing object. Both these things led to the sensor not working as expected. Additionally, changes made last commit also helped to fix the issues introduced by the initial efficiency commit.
    [Lap_Time_Display_Custom_Final.ino]
